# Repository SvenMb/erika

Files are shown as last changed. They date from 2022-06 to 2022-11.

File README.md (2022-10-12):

## Use your erika typewriter as keyboard and printer (and mouse)

System overview

### Compatible systems

You need a system with uinput (like linux), python3 and a TTL-serial port with CTS (can be done via usb-serial adapter).

I use a raspberry, because of this everything will be tested and prepared to use it this way. 

### Install

see [here](doc/install.md)

### Printing

It is possible to print with utf-8 coding and cp858 (cp850 + €) coding

### Use together with RunCPM

with a very small patch you can use the erika as "lst:" in RunCPM. Printing will be done without delay, every char will be printed directly.

Patch file: [RunCPM.patch](doc/RunCPM.patch)

orig Repository: [https://github.com/MockbaTheBorg/RunCPM.git](https://github.com/MockbaTheBorg/RunCPM.git)

#### Addendum

- serial printing doesnẗ work on DEBIAN sid via cups, use lpd or this hack until I implemented it directly:
~~~
socat TCP-LISTEN:9100 GOPEN:/dev/erika/erika
~~~

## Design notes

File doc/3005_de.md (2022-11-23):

# German keyboard layout for Erika 3005,3006,3015,3016
*(and compatible)*

To use the typewriter keyboard as computer keyboard some keys are
mapped to different chars, since these are needed for computer use.

Especialy for terminal use, you will need control keys, most of them
are mapped to CODE+A - CODE-Z, see below for more details.

The 3005 typewriter has an aditional layer via MODE key avaiable. 
So I could add special keys like cursor and mouse.
The cursor keys are arranged to wasd standard.
See below for details.

## Overview layout

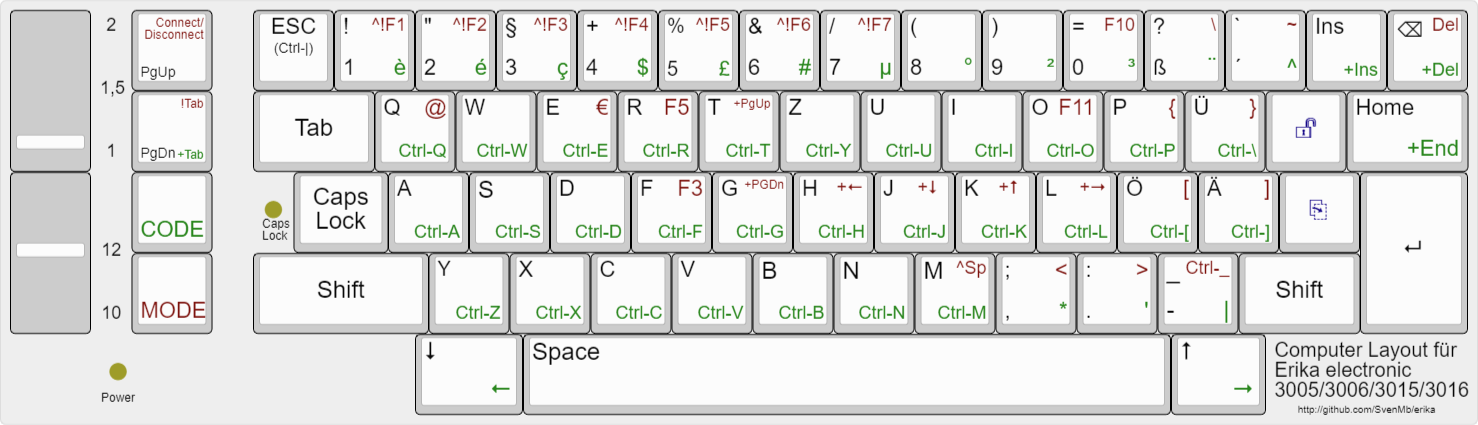
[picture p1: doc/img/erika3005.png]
Erika 3005 keyboard

(created with http://www.keyboard-layout-editor.com/)

notes:
- on 3006and 3016 the switches are labeled different, but they aren't used in computer connection any way
- mouse keys are not included in this picture
- Connect/Disconnect's the typewriter from computer as keyboard or standalone use as typewriter
- red description means the key is pressed together with MODE-key
- green description means the key is pressed together with  
- \+ means Shift, so +Tab means it sends Shift+Tab
- ! means Alt, so !Tab means it sends Alt+Tab
- ^ means CTRL
- the above can be combined, so ^!F1 means CTRL-ALT-F1, which switches to first console on Linux
- ^Sp means CTRL-Space which is "set-mark" in emacs
- arrow mean cursor key
- ⌫ means Backspace or DeleteLeft
<!-- - ![unlock](https://raw.githubusercontent.com/ijprest/keyboard-layout-editor/master/font-src/kbd-webfont/Unicode-Lock-Open-1.svg) -->
- unlock this is border unlock key, currently not used
- unlock this is form feed key, it allows to load paper even in connected mode
- CTRL-Y and CTRL-Z are swapped, so wordstar diamond works as intended

## Standard chars
- all char keys just generate that char pictured on the key
- acute key is used to generate composed chars (like é,è,ê)
- shift-ß is also used to generate composed chars (like ë)

### additional chars
key code | key                  | char generated
-----|--------------------------|------------
0xdf | MODE+,			| <
0xe3 | MODE+.			| >
0xe5 | MODE+P			| {
0xe6 | MODE+Ö			| [
0xe8 | MODE+ß			| \
0xe9 | MODE+Ü			| }
0xea | MODE+Ä			| ]
0xec | MODE+`			| ~
0xc1 | MODE+Q			| @
0xc9 | MODE+E			| €

### special functions

 key code | key | function
------|-----|----------
0x72  | backstep/backspacer	| insert
0x75  | half line forward	| cursor down
0x76  | half line backward	| cursor up
0x77  | Carriage return 	| Enter
0x79  | Tab			| Tab
0x7a  | T+			| Page up
0x7b  | T-			| Page down
0x7e  | Margin setting left 	| ESC
0x80  | Margin release 		|
0x83  | Form feed/paper insert	| forward form feed
0x84  | 1 line spacing		|
0x85  | 1,5 line spacing	|
0x86  | 2 lines spacing		|
0x87  | 10 cpi/ type spacing	|
0x88  | 12 cpi/ type spacing	|
0xae  | backspace/correction	| Backspace
0xaf  | REL			| Home

#### special chars with CODE

 key code | key | function
------|-----|----------
0x74  | CODE backstep/backspace   | shift insert
0xf7  | CODE backspace/correction | shift delete
0x7f  | Margin setting right	  | CTRL-ESC
0x7c  | CODE T-			  | shift-tab
0x7d  | CODE T+			  | mouse step width
0x81  | CODE micro line forward	  | cursor left
0x82  | CODE micro line backward  | cursor right
0xad  | CODE REL		  | shift End

#### special chars with MODE
 key code | key | function
----------|-----|----------
0xfb  | MODE backspace/correction | delete
0xf4	  | MODE T+    | switch computer/typewriter
0xf5	  | MODE T-    | ALT-tab (switch window)
0xc1	  | MODE 1     | CTRL-ALT-F1 (switch tty1)
0xc4	  | MODE 2     | CTRL-ALT-F2 (switch tty2)
0xc8	  | MODE 3     | CTRL-ALT-F3 (switch tty3)
0xcc	  | MODE 4     | CTRL-ALT-F4 (switch tty4)
0xd0	  | MODE 5     | CTRL-ALT-F5 (switch tty5)
0xd4	  | MODE 6     | CTRL-ALT-F6 (switch tty6)
0xd8	  | MODE 7     | CTRL-ALT-F7 (switch tty7)
0xdc	  | MODE 8     |
0xe0	  | MODE 9     |
0xe4	  | MODE 0     | F10 (Menu in Emacs)
0xe8	  | MODE O     | F11 (fullscreen)
0xcd	  | MODE R     | F5  (refresh)
0xce	  | MODE F     | F3  (find)
0xd3  | MODE M      | CTRL-Space (set-mark emacs)

### CTRL keys
**from CODE A until CODE Z - generate corresponding CTRL-A until CTRL-Z**

 key code | key    | function
----------|--------|----------
0xbb+0xe9 | CODE-Ü | CTRL-\ 0x1c
0xbb+0xe6 | CODE-Ö | CTRL-[ 0x1b
0xbb+0xea | CODE-Ä | CTRL-] 0x1d (telnet-Escape)
          |        | CTRL-^ 0x1e (not implemented, use ESC)
0xe7	     | MODE-_ | CTRL-_ 0x1f

### Cursor keys
key code | key | function
---------|-----|----------
0x75  | half line forward	  | cursor down
0x76  | half line backward	  | cursor up
0x81  | CODE micro line forward	  | cursor left
0x82  | CODE micro line backward  | cursor right
0x7a  | T+			  | Page up
0x7b  | T-			  | Page down
0xe2  | MODE L 			  | shift cursor rigth
0xda  | MODE J 			  | shift cursor down
0xde  | MODE K 			  | shift cursor up
0xd6  | MODE H 			  | shift cursor left
0xd1  | MODE T 			  | shift page up
0xd2  | MODE G 			  | shift page down
0xeb  | REL 			  | HOME
0xee  | CODE REL		  | END

### Mouse keys
key code | key          | function
---------|--------------|----------
0x7d	 | CODE T+	| step width for mouse (1,4,8,16)
0xc3 	 | MODE Y	| mouse btn left
0xcb 	 | MODE C  	| mouse btn right 
0xc7 	 | MODE X	| mouse btn left on (tap step down for off)
0xcf 	 | MODE V	| mouse btn right on (tap step up for off)
0xc2 	 | CODE A 	| mouse left
0xc6 	 | CODE S 	| mouse down
0xc5 	 | CODE W 	| mouse up
0xca 	 | CODE D 	| mouse right

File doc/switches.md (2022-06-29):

# keycodes and states for switches

## keycodes send by erika 3004/3005/3006/3015/3016

Even if the switches on the left side of the keyboard have different meaning on 3005 and 3006 they send same key codes.
Only 3004 send different codes.

I have tested all the erika models  and got that table:

switch                   | 3004 | 3005 | 3006 | 3015 | 3016
-------------------------|------|------|------|------|------
upper switch, upper pos  | 0x86 | 0xf8 | 0xf8 | 0xf8 | 0xf8
upper switch, middle pos | 0x85 | 0xfe | 0xfe | 0xfe | 0xfe
upper switch, lower pos  | 0x84 | 0xf9 | 0xf9 | 0xf9 | 0xf9
lower switch, upper pos  | 0x88 | 0xff | 0xff | 0xff | 0xff
lower switch, lower pos  | 0x87 | 0xfa | 0xfa | 0xfa | 0xfa

so from 3005 and up there is a special code for the switches, while 3004 send it as state of typewriter.

## when sending the disconnect code (0x92)

*this code disconnects the typewriter from the keyboard, for computer use and send information about the state of the typewriter*

### erika 3004

* sends only state of typewriter and switches together
  * state of cpi, one of:
    * 0x87 - 10cpi
    * 0x88 - 12cpi
  * state of line spacing, one of
    * 0x84 - 1 line
    * 0x85 - 1,5 line
    * 0x86 - 1,5 line

*be aware erika 3004 may send 0x85 (0x85) first and then the correct line spacing.*

### erika 3005, 3006, 3015, 3016

* sends state of typewriter
  * state of cpi, one of:
    * 0x87 - 10cpi
    * 0x88 - 12cpi
    * 0x89 - 15cpi
  * state of line spacing, one of
    * 0x84 - 1 line
    * 0x85 - 1,5 line
    * 0x86 - 1,5 line

* sends state of switches
  * one byte for each switch (2), see above table

### Conclusion

based on this it is possible to auto switch between 3004 and 3005 (and other models with mode key)

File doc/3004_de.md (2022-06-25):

# German keyboard layout for Erika 3004
*(and compatible)*

To use the typewriter keyboard as computer keyboard some keys are
mapped to different chars, since these are needed for computer use.
(see changed chars)

Especialy for terminal use, you will need control keys, most of them
are mapped to CODE+A - CODE-Z, see below for more details.

You will probably need special keys like cursor and I liked to
emulate a mouse. This is realized in second layer of the keyboard
you have to switch between them. The cursor keys are arranged like
the wordstar diamond. See below for details.

## 1st layer
- nearly all char keys just generate that char pictured on the key
- acute key is used to generate composed chars (like é,è,ê)
- 2nd layer shift-ß is also used to generate composed chars (like ë)

### switch to 2nd layer
key code | key | function
---------|-----|----------
0x78 | backstep left to enter	| switch to 2nd layer

### changed chars
key code | key                  | char generated
-----|--------------------------|------------
0x46 | CODE+1 (è)		| @
0x44 | CODE+2 (é)		| ~
0x45 | CODE+3 (ç)		| €
0x06 | CODE+5 (£)		| <
0x07 | CODE+7 (µ)		| >
0x03 | CODE+ß (")		| \
0xe9 | CODE+Ü			| {
0x80 | Margin release		| } (works with CODE too)
0xe6 | CODE+Ö			| [
0xea | CODE+Ä			| ]

### special functions

 key code | key | function
------|-----|----------
0x72  | backstep/backspacer	| insert
0x75  | half line forward	| cursor down
0x76  | half line backward	| cursor up
0x77  | Carriage return 	| Enter
0x79  | Tab			| Tab
0x7a  | T+			|  CTRL-_ (undo in emacs)
0x7b  | T-			| shift Tab
0x7e  | Margin setting left 	| ESC
0x80  | Margin release 		| } (that char!)
0x83  | Form feed/paper insert	| forward form feed
0x84  | 1 line spacing		|
0x85  | 1,5 line spacing	|
0x86  | 2 lines spacing		|
0x87  | 10 cpi/ type spacing	|
0x88  | 12 cpi/ type spacing	|
0xae  | backspace/correction	| Backspace
0xaf  | REL			| Delete

#### special chars with CODE

 key code | key | function
------|-----|----------
0x74  | CODE backstep/backspace	| shift insert
0x7f  | Margin setting right	| CTRL-ESC
0x7c  | CODE T-			| ALT-Tab
0x7d  | CODE T+			| switch computer/typewriter
0x81  | CODE micro line forward	| cursor left
0x82  | CODE micro line backward| cursor right
0xad  | CODE REL		| shift Delete

**from CODE A until CODE Z - generate corresponding CTRL-A until CTRL-Z**

## 2nd layer

Cursor and mouse keys stay in 2nd-layer so you can move around easiliy.

### switch back to 1st layer
key code | key | function
---------|-----|----------
0x77     | Carriage return	| switch back to 1st layer

*and all other keys not mentioned here as cursor or mouse key*

### Cursor keys
key code | key | function
---------|-----|----------
0x14 | shift D 			| shift cursor rigth
0x20 | shift C 			| shift page down
0x26 | shift X 			| shift cursor down
0x33 | shift S 			| shift cursor left
0x34 | shift E 			| shift cursor up
0x36 | shift R 			| shift page up
0x4c | W 		| Home
0x51 | Y 			| End
0x53 | D 			| cursor right
0x57 | C 			| page down
0x58 | S 			| cursor left
0x59 | R 			| page up
0x5a | E 			| cursor up
0x5f  | X 			| cursor down

### Mouse keys
key code | key | function
---------|-----|----------
0x75 | half line forward	| mouse btn left
0x76 | half line backward  	| mouse btn right 
0x7a | T+			| step width for mouse (1,4,8,16)
0x81 | CODE micro line forward	| mouse btn left on (tap step down for off)
0x82 | CODE micro line backward | mouse btn right on (tap step up for off)
0xc3 | CODE Y 			| mouse down+left
0xc5 | CODE W 			| mouse up+left
0xc6 | CODE S 			| mouse left
0xc7 | CODE X 			| mouse down
0xc9 | CODE E 			| mouse up
0xca | CODE D 			| mouse right
0xcb | CODE C 			| mouse down+right
0xcd | CODE R 			| mouse up+right

### Function keys
**starting from here all keys switch back to 1st layer after using**

key code | key | function
---------|-----|----------
0x11 | 1 			| F1
0x10 | 2 			| F2
0x0f | 3 			| F3
0x0e | 4 			| F4
0x0c | 5 			| F5
0x0b | 6 			| F6
0x0a | 7 			| F7
0x09 | 8 			| F8
0x08 | 9 			| F9
0x0d | 0 			| F10
0x47 | ß 			| F11
0x29 | ` 			| F12
0x46 | CODE 1 			| CTRL ALT F1
0x44 | CODE 2 			| CTRL ALT F2
0x45 | CODE 3 			| CTRL ALT F3
0x48 | CODE 4 			| CTRL ALT F4
0x06 | CODE 5 			| CTRL ALT F5
0x41 | CODE 6 			| CTRL ALT F6
0x07 | CODE 7 			| CTRL ALT F7
0x39 | CODE 8 			| CTRL ALT F8
0x15 | CODE 9 			| CTRL ALT F9
0x23 | CODE 0 			| CTRL ALT F10

### some more CTRL-keys and chars

key code | key | function/char
---------|-----|---------------
0xe6 | CODE Ö 			| ^[, (CTRL-[, 0x1b | ESC)
0x03 | CODE ß 			| ^\, (CTRL-\, 0x1c)
0xea | CODE Ä 			| ^], (CTRL-], 0x1d)
0x19 | CODE ` 			| ^^, (CTRL-^, 0x1e)
0x27 | CODE _ 			| ^_, (CTRL-_, 0x1f)
0x3d | shift 3			| ç, (that char)
0x35 | shift ß			| ", to generate composed char
0x7d | CODE T+    | "shutdown -h now" if next key is y

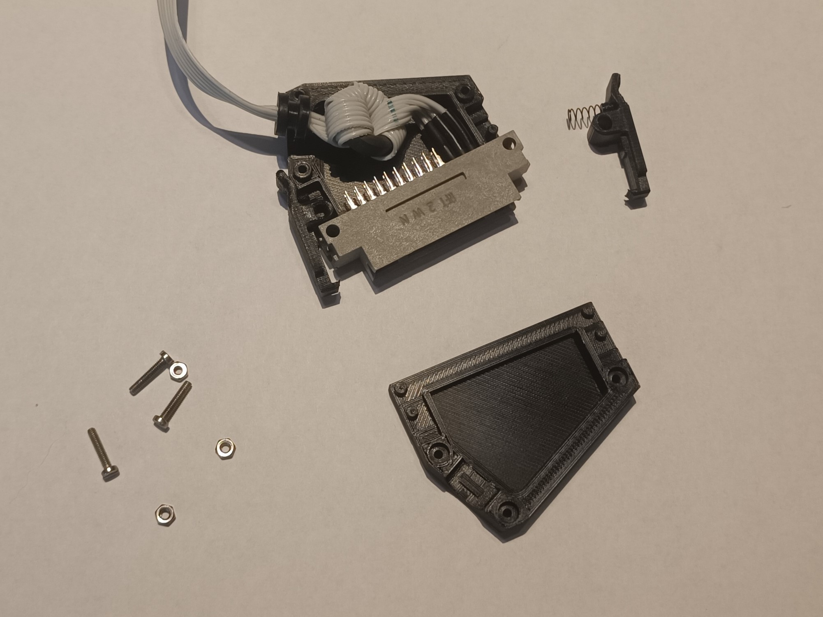
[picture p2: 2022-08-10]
hardware/efs26_con01.jpg

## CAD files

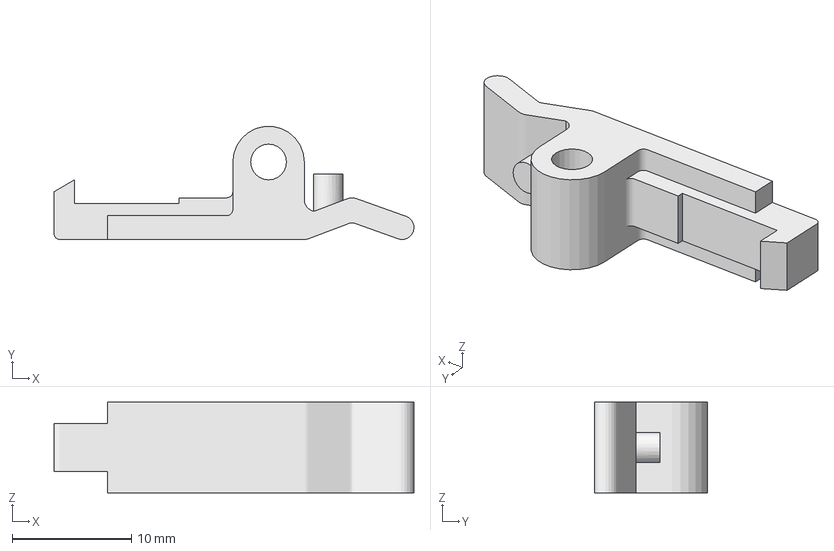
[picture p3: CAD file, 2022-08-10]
hardware/efs26_gehaeuse_hebel.FCStd
30.2 x 9.48 x 7.60 mm

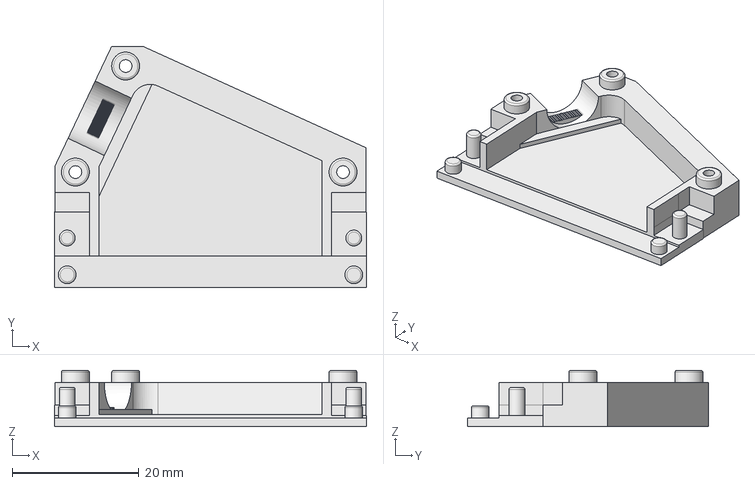
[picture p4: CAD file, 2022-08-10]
hardware/efs26_gehaeuse_oben.FCStd
49.2 x 38.0 x 8.90 mm

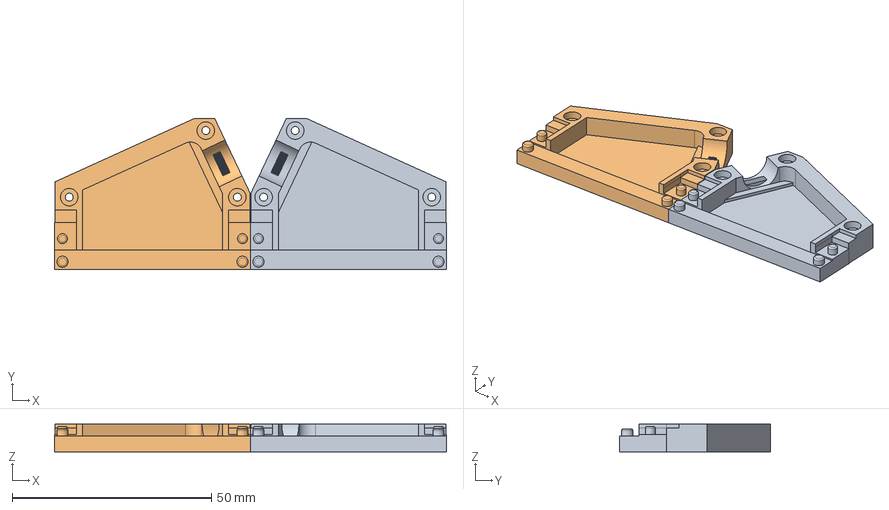
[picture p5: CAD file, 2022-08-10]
hardware/efs26_gehaeuse_unten.FCStd
98.4 x 38.0 x 7.00 mm
untereSchale
Fillet (Mirror #1)

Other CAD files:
hardware/efs26_gehaeuse_Hebel.stl
hardware/efs26_gehaeuse_oben.stl
hardware/efs26_gehaeuse_unten.stl

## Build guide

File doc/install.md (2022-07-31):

## Install erika service

### Prerequisites

You will need a installed linux system with working /dev/uinput and serial
connection with hardware rts/cts flow control.
If you like to use the service definitions, you also need systemd, else 
you need to integrate it in your system by yourself.

#### example raspberry Erika on GPIO header

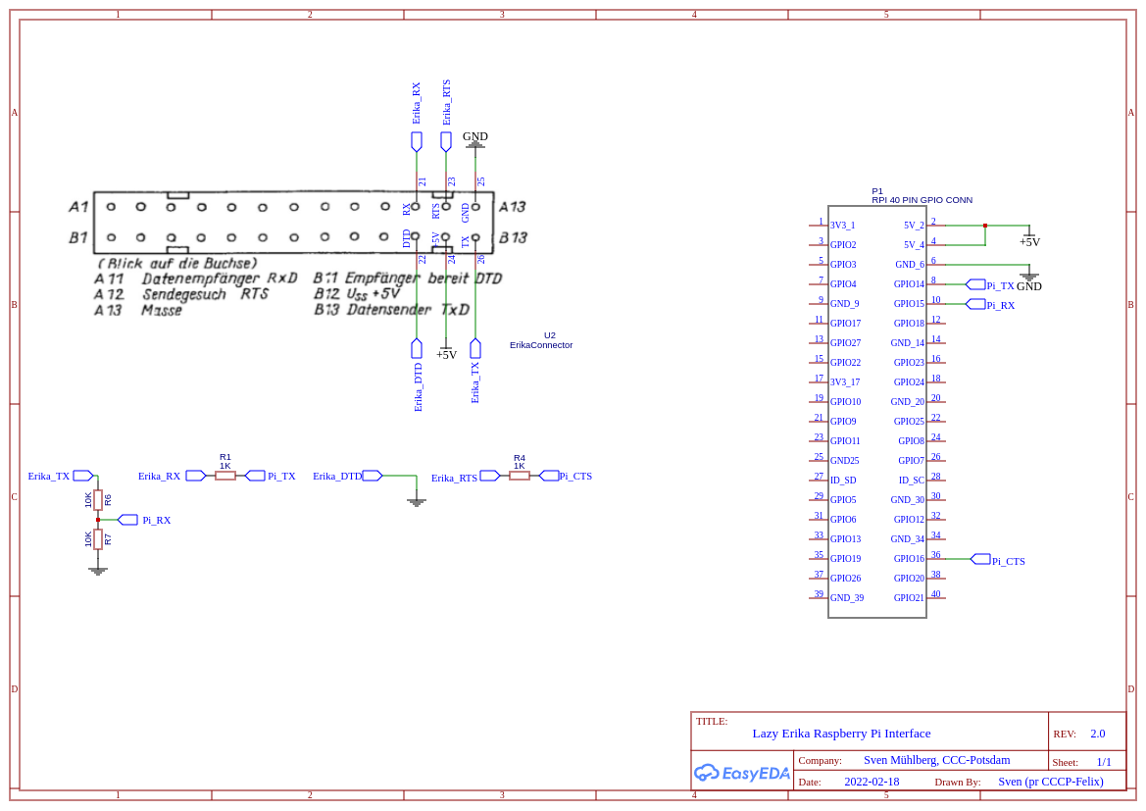
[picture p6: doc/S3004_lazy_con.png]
Erika2raspberry

*5v should only be connected if you like to power the raspberry from you Erika. And this should only be done with a low power raspi like Zero, Zero W maybe with Zero W 2.* 

1. install raspberry
2. take care, that serial port is enabled, but login shell on serial is off. keymap should be de for 105keys keyboard, since currently only german keymap is available. 
(all done via raspi-config)
3. copy the uart-cts to overlays  
`sudo cp raspberry/boot/overlays/uart-cts.dtbo /boot/overlays/`  
4. add following lines to config.txt (first one should already be there)
```
enable_uart=1
dtoverlay=miniuart-bt
dtoverlay=uart-cts
```
This makes sure that uart is enabled, the right uart is assigned to gpio port (and bluetooth get the simpler one and will also work).
It activates CTS on GPIO16 (pin 36 on gpio header)

#### known problems with ch34x serial-usb adapter

In case you like to use a ch340 USB-Serial adapter, then this info is for you.

The ch34x has a CTS pin but even when CTS pin is avaiable on your adapter hardware flow controll probably won't work, since default linux kernel driver ignores CTS and sends data even when it should stop.

A working driver for current linux kernel can be found here:

[https://github.com/juliagoda/CH341SER](https://github.com/juliagoda/CH341SER)

### manual installation from https://git.muehlberg.net

1. Verzeichnis erstellen
```sh
cd
mkdir -pv Development/SvenMb
cd Development/SvenMb
```
1. extract certificate for git.muehlberg.net:  
```sh
echo -n \\ | openssl s_client -showcerts -connect git.muehlberg.net:443 \
2>/dev/null  | sed -ne '/-BEGIN CERTIFICATE-/,/-END CERTIFICATE-/p' \
> mbnet_cert.pem
```
2. add the cert to your git config  
`git config --global http."https://git.muehlberg.net:443/".sslCAInfo $(pwd)/mbnet_cert.pem`
3. clone project directory  
`git clone https://git.muehlberg.net/SvenMb/erika.git`
4. change to project directory  
`cd erika`
5.  install python-evdev  
`sudo apt install python3-evdev` (z.Z. nur v1.4) oder 
`sudo pip3 install evdev` (aktuell v1.6)
6.  copy src to /var/lib/erika  
`sudo cp -R src /var/lib/erika`
7.  link /var/lib/erika/erika_set.py to /usr/bin/
`sudo ln -s /var/lib/erika/erika_set.py /usr/bin/`
8. copy systemd/system/erika.service to /etc/systemd/system/erika.service  
`sudo cp systemd/system/erika.service /etc/systemd/system/erika.service`
9. copy systemd/default/erika.service to /etc/default/erika  
`sudo cp systemd/default/erika /etc/default/erika`
10. change to cups directory
`cd cups`
11. start cups install script
`./create_ppd.sh`

### adapt to local system

* you can set different serial ports and other options in /etc/default/erika
* you can adjust the virtual printer port permission and name in /var/lib/erika/setperm.sh

### test service

* start erika service  
  `sudo systemctl start erika`
* get status of erika service  
  `sudo systemctl status erika`
* stop erika service  
 `sudo systemctl stop erika`

### enable service for autostart 

* enable service for default start  
  `sudo systemctl enable erika`

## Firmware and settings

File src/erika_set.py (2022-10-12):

#!/usr/bin/env python3
# -*- coding: utf-8 -*-
#
#  erika_set.py
#  
#  Copyright 2022  <sven@muehlberg.net>
#  
#  

import serial
import os, sys, getopt

def eprint(*args, **kwargs):
    print(*args, file=sys.stderr, **kwargs)

def main(argv):

    s          = serial.Serial()
    s.port     = '/dev/erika/erika'
    
    verbose    = 0
    cpi        = None
    linestep   = None
    maxlines   = None
    maxcolumns = None
    tabstop    = None
    charset    = None
    firstcol   = None
    formfeed   = False
    wrap       = None
    backsteps  = None

    # comand line args
    try:
        opts, args = getopt.getopt(argv,"hvd:i:s:l:c:f:w:t:z:B:p",
            ["help","verbose","device=","cpi=","halflines=","columns=","firstcolumn=","linespacing=","wrap=","tabstop=","charset=","backsteps=","formfeed"])
    except getopt.GetoptError:
        eprint('erika.py argument error')
        eprint('use erika_set.py -h for help')
        sys.exit(2)

    if len(opts) == 0:
        eprint('erika_set.py no argument error')
        eprint('use erika_set.py -h for help')
        sys.exit(2)

    for opt, arg in opts:
        if opt in ('-h', '--help'):
            print('erika_set.py\n')
            print('USAGE:')
            print('\terika_set.py [OPTIONS]\n')
            print('OPTIONS:')
            print('\t-h, --help\t\tprint help information')
            print('\t-v, --verbose\t\tbe more verbose')
            print('\t\tcan be added multiple times to be even more verbose')
            print('\t-d, --device <device>\tserial device to use')
            print('\t\tdefault: ', s.port )
            print('\t\tif \'-\' is given as devicename, stdout is used')
            print('\t-i, --cpi\t\tcharacters per inch, char density')
            print('\t\tuse 10, 12 with normal daisy wheel, 15 possible on\n\t\t3005(and up) with special daisy wheel')
            print('\t-s, --linespacing\t\thalf lines used for one printed line')
            print('\t\tpossible spacing: 2, 3, 4')
            print('\t-l, --halflines\t\tmax half lines per paper sheet')
            print('\t\tA4 - 120 half lines')
            print('\t-c, --columns\t\tmax half char per line')
            print('\t\trecommended:')
            print('\t\tA4 - 84 columns on 12 cpi')
            print('\t\tmax 150 columns')
            print('\t-f, --firstcolumn\t\tfirst column')
            print('\t\trecommended 10 for 10cpi, 12 for 12cpi and 15 for 15cpi')
            print('\t\tstarting with 1')
            print('\t-w, --wrap\t\tLinewrapping on or off')
            print('\t\t1 for wrapping to long lines and 0 for truncating')
            print('\t-t, --tabstop\t\tdistance tabstops')
            print('\t\trecommended 4 or 8')
            print('\t-B, --backsteps\t\thalf steps backward after formfeed')
            print('\t\tpossible between 0 and 9')
            print('\t-z, --charset\t\textra charset (Zeichenkodierung)')
            print('\t\tselectable from cp858 and if6000')
            print('\t\tmain charset is always utf-8')
            print('\t-p, --formfeed\t\tform feed to change paper')
            print('\t\tno options')
            sys.exit()
        elif opt in ('-d', '--device'):
            s.port = arg
        elif opt in ('-v', '--verbose'):
            verbose += 1
        elif opt in ('-i', '--cpi'):
            if arg in ('10','12','15'):
                cpi = arg
            else:
                eprint('ERROR: Wrong cpi:', arg)
                eprint('ERROR: only 10, 12 or 15 possible')
                sys.exit(2)
        elif opt in ('-s', '--linespacing'):
            if arg in ('2', '3', '4'):
                linestep=arg
            else:
                eprint('ERROR: wrong linespacing:',arg)
                eprint('ERROR: only 2, 3 or 4 possible')
                sys.exit(2)
        elif opt in ('-l', '--halflines'):
            if arg.isnumeric() and int(arg) < 256:
                maxlines = int(arg)
            else:
                eprint('ERROR: wrong halflines ',arg,' used.')
                sys.exit(2)
        elif opt in ('-c', '--columns'):
            if arg.isnumeric() and int(arg) < 151:
                maxcolumns = int(arg)
            else:
                eprint('ERROR: wrong columns ',arg,' used.')
                sys.exit(2)
        elif opt in ('-f','--firstcolumn'):
            if arg.isnumeric() and int(arg) > 0:
                firstcol = int(arg)
            else:
                eprint('ERROR: wrong firstcolumn',arg)
                sys.exit(2)
        elif opt in ('-w','--wrap'):
            if arg in ('0','1'):
                wrap = arg
            else:
                eprint('ERROR: wrong LineWrap:',arg)
                eprint('ERROR: only 0 or 1 possible here.')
                sys.exit(2)
        elif opt in ('-t', '--tabstop'):
            if arg.isnumeric() and int(arg) > 0 and int(arg) < 17:
                tabstop = int(arg)
            else:
                eprint('ERROR: wrong tabstop:',arg)
                eprint('ERROR: tabstop should between 1 and 16 spaces')
                sys.exit(2)
        elif opt in ('-B', '--backsteps'):
            if arg.isnumeric() and int(arg) < 10:
                backsteps = int(arg)
            else:
                print('wrong backsteps ',arg,' used.')
                sys.exit(2)
        elif opt in ('-z', '--charset'):
            if arg in ('cp858','if6000'):
                charset = arg
            else:
                eprint('ERROR: wrong extra charset',arg)
                sys.exit(2)
        elif opt in ('-p','--formfeed'):
            formfeed = True



    # info about current options         
    if verbose:
        eprint('DEBUG: Erika device:', s.port)
        eprint('DEBUG: verbose      :',verbose)
        if cpi:
            eprint('DEBUG: cpi          :', cpi)
        if maxcolumns:
            eprint('DEBUG: maxcolumns   :', maxcolumns)
        if linestep:
            eprint('DEBUG: linestep     :', linestep)
        if maxlines:
            eprint('DEBUG: maxlines     :', maxlines)
        if firstcol:
            eprint('DEBUG: firstcolumn  :', firstcol)
        if wrap:
            eprint('DEBUG: tabstop      :', wrap)
        if tabstop:
            eprint('DEBUG: tabstop      :', tabstop)
        if charset:
            eprint('DEBUG: extra charset:', charset)
        if backsteps!=None:
            eprint('DEBUG: backsteps    :', backsteps)
        if formfeed:
            eprint('DEBUG: formfeed     :', formfeed)

    # open erika port
    if s.port != '-':
        try:
            s.open()
        except serial.SerialException as e:
            eprint(e)
            eprint('CRIT: erika daemon not running or wrong device name')
            eprint('CRIT: use erika_set.py -h for help')
            sys.exit(2)
    # or stdout
    else:
        s = os.fdopen(sys.stdout.fileno(), 'wb',closefd=False)
    # cpi
    if cpi:
        if cpi == '15':
            s.write(b'\x1bO')
        elif cpi == '12':
            s.write(b'\x1bN')
        else: # should be 10 now
            s.write(b'\x1bM')
        eprint('INFO: cpi set to        :', cpi)

    # linespacing
    if linestep:
        if linestep == '2':
            s.write(b'\x1b3')
        elif linestep == '3':
            s.write(b'\x1b4')
        else: # should be 4 now
            s.write(b'\x1b5')
        eprint('INFO: linespacing set to:', linestep)

    # maxlines
    if maxlines:
        s.write(b'\x1bL' + maxlines.to_bytes(1,'big'))
        eprint('INFO: maxlines set to:', maxlines)

    # maxcolumns
    if maxcolumns:
        s.write(b'\x1bC' + maxcolumns.to_bytes(1,'big'))
        eprint('INFO: maxcolumns set to:', maxcolumns)

    # firstcolumn
    if firstcol:
        s.write(b'\x1bF' + firstcol.to_bytes(1,'big'))
        eprint('INFO: firstcolumn set to:', firstcol)

    # wrap
    if wrap:
        if wrap == '0':
            s.write(b'\x1bw')
        else:
            s.write(b'\x1bW')
        eprint('INFO: wrap set to:', wrap)

    # tabstop
    if tabstop:
        s.write(b'\x1bT' + tabstop.to_bytes(1,'big'))
        eprint('INFO: tabstop set to:', tabstop)

    # charset
    if charset:
        if charset == 'cp858':
            s.write(b'\x1bZ')
        else: # should be if6000
            s.write(b'\x1bz')
        eprint('INFO: charset set to:', charset)

    # backsteps
    if backsteps!=None:
        s.write(b'\x1bB' + backsteps.to_bytes(1,'big'))
        eprint('INFO: backsteps set to:', backsteps)
    
    # form feed
    if formfeed:
        s.write(b'\f')
        eprint('INFO: form feed sent to erika')
        eprint('INFO: use \'margin release\' key when finished')

    s.flush()
    s.close()
    sys.stderr.flush()

    
if __name__ == "__main__":
    main(sys.argv[1:])

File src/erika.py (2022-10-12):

#!/usr/bin/env python3
# -*- coding: utf-8 -*-
#
#  erika.py
#  
#  Copyright 2022  <sven@muehlberg.net>
#  
#  

from erika.erika import Erika
import erika.vprint as V
import sys, getopt

verbose = 0

def main(argv):
    
    e = Erika()

    V.init()
    
    # comand line args
    try:
        opts, args = getopt.getopt(argv,"hved:b:k:p:i:s:l:c:f:wt:B:z:",
            ["help","verbose","echo","device=","baudrate=","keyboard=",'setperm=','cpi=','linespacing=','halflines=','columns=','firstcolumn=','wrap','tabstop=','backsteps=','charset='])
    except getopt.GetoptError:
        print('erika.py argument error')
        print('use erika.py -h for help')
        sys.exit(2)
    for opt, arg in opts:
        if opt in ('-h', '--help'):
            print('erika.py\n')
            print('USAGE:')
            print('\terika.py [OPTIONS]\n')
            print('OPTIONS:')
            print('\t-h, --help\t\tprint help information')
            print('\t-v, --verbose\t\tbe more verbose')
            print('\t\tcan be added multiple times to be even more verbose')
            print('\t-e, --echo\t\tconnect keyboard to typewriter')
            print('\t-d, --device <device>\tserial device to use')
            print('\t\tExample device name: /dev/ttyAMA0 or /dev/ttyUSB0')
            print('\t\tdefault: ', e.serial.port )
            print('\t-b, --baudrate <rate>\tbaudrate for erika')
            print('\t\terika manual says don\'t change!')
            print('\t\tExample baudrate: 1200')
            print('\t\tdefault: ', e.serial.baudrate )
            print('\t-k, --keyboard <map>\tkeyboard map to use')
            print('\t\tpossible keyboards: de, 3004_de, 3005_de, none')
            print('\t\tdefault: ', e.keyboard )
            print('\t\tuse \'de\' for autodetect machine type (only\n\t\timplemented language currently)')
            print('\t\tuse \'none\' if you don\'t want to use the erika\n\t\tkeyboard for input')
            print('\t\tcurrently implemented 3004_de and 3005_de.')
            print('\t\t3005, 3006, 3015, 3016 use the same keycodes.')
            print('\t-p, --setperm <script>\tscript to create link and set\n\t\tpermission for virtual lp-device')
            print('\t\tExample: sudo lp_setperm')
            print('\t\tdefault: ', e.lpsetperm )
            print('\t-i, --cpi\t\tcharacters per inch, char density')
            print('\t\tdefault: ', int(60/e.charstep))
            print('\t\tuse 10, 12 with normal daisy wheel, 15 possible on\n\t\t3005(and up) with special daisy wheel')
            print('\t-s, --linespacing\t\thalf lines used for one printed line')
            print('\t\tpossible spacing: 2, 3, 4')
            print('\t\tdefault: ',e.linestep)
            print('\t-l, --halflines\t\tmax half lines per paper sheet')
            print('\t\tdefault: ', e.maxlines)
            print('\t\tA4 - 120 half lines')
            print('\t-c, --columns\t\tmax half char per line')
            print('\t\tdefault: ', int(e.maxcolumns/e.charstep))
            print('\t\tA4 - 84 columns on 12 cpi')
            print('\t-f, --firstcolumn\t\tfirst column')
            print('\t\tdefault: ', e.firstcol)
            print('\t\trecommended 10 for 10cpi, 12 for 12cpi and 15 for 15cpi')
            print('\t\tstarting with 1')
            print('\t-w, --wrap')
            print('\t\tdefault: off')
            print('\t\tIf this option is given, to long lines will be wrapped around,')
            print('\t\tif not, they will be truncated.')
            print('\t-t, --tabstop\t\tdistance tabstops')
            print('\t\tdefault: ', e.tabstop)
            print('\t\trecommended 4 or 8')
            print('\t-B, --backsteps\t\thalf steps backward after formfeed')
            print('\t\tdefault: ', e.backsteps)
            print('\t\tpossible between 0 and 9')
            print('\t-z, --charset\t\textra charset (Zeichenkodierung)')
            print('\t\tdefault:',e.charset)
            print('\t\tselectable from cp858 and if6000')
            print('\t\tmain charset is always utf-8')
            sys.exit()
        elif opt in ('-e','--echo'):
            e.echo = True
        elif opt in ('-d', '--device'):
            e.serial.port = arg
        elif opt in ('-b', '--baudrate'):
            e.serial.baudrate = arg
        elif opt in ('-k', '--keyboard'):
            e.keyboard = arg
        elif opt in ('-p', '--setperm'):
            e.lpsetperm = arg
        elif opt in ('-i', '--cpi'):
            if arg in ('10','12','15'):
                e.charstep=int(60/int(arg))
            else:
                print('wrong cpi',arg,'used.')
                sys.exit(2)
        elif opt in ('-s', '--linespacing'):
            if arg in ('2', '3', '4'):
                e.linestep=int(arg)
            else:
                print('wrong linespacing ',arg,' used.')
                sys.exit(2)
        elif opt in ('-l', '--halflines'):
            if arg.isnumeric():
                e.maxlines = int(arg)
            else:
                print('wrong halflines ',arg,' used.')
                sys.exit(2)
        elif opt in ('-c', '--columns'):
            if arg.isnumeric():
                e.maxcolumns = int(arg)*charstep - 1
            else:
                print('wrong columns ',arg,' used.')
                sys.exit(2)
        elif opt in ('-f','--firstcolumn'):
            if arg.isnumeric() and int(arg) > 0:
                e.firstcol = int(arg)
            else:
                print('wrong firstcolumn',arg)
                sys.exit(2)
        elif opt in ('-w','--wrap'):
            e.wrap = True
        elif opt in ('-t', '--tabstop'):
            if arg.isnumeric():
                e.tabstop = int(arg)
            else:
                print('wrong tabstop ',arg,' used.')
                sys.exit(2)
        elif opt in ('-B', '--backsteps'):
            if arg.isnumeric() and int(arg) < 10:
                e.backsteps = int(arg)
            else:
                print('wrong backsteps ',arg,' used.')
                sys.exit(2)
        elif opt in ('-v', '--verbose'):
            print('verbose arg:',arg)
            V.inc()
        elif opt in ('-z', '--charset'):
            e.charset = arg
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

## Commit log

2022-06-13 added socat script with virtual serial device for devlopment
2022-06-20 Uebersetzung der keyboarddaten von erika begonnen
2022-06-23 modified uinput name handling; removed wheel option, since this program is not printing, just forwarding prints
2022-06-23 option wheel removed...
2022-06-23 added reboot on MODE+Randlösen
    [erika.py]
2022-06-24 change to mouse button handling
2022-06-24 added all keys (but currently empty on 2nd layer)
2022-06-24 small fix in s3004 keyboard
    [s3004_de.py]
2022-06-28 add info for raspberry pi
2022-06-29 doc added for switches
2022-06-29 begin rework keyboard, goal is to autodetect keyboard/typewriter model
    [erika.py, s3004_de.py, s3005_de.py]
2022-07-01 changed schematics
2022-07-01 added some infos to power raspberry from erika
2022-07-02 printing of utf-8/cp850 added
2022-07-02 printing now working
2022-07-03 line feed and line break when trying to print over paper borders added switching cpi and line spacing added verbose handling changed
2022-07-03 add carriage return if explicit form feed
2022-07-03 added charset from original if6000 and option + esc sequence to switch
2022-07-09 added stdout as device and made messages compatibel to cups
2022-07-11 cups driver nearly finished
2022-07-11 Install cups ppd/filter added
2022-07-11 backsteps implemented, some fixes
    [erika.py, erika_set.py]
2022-07-11 added filter for html and pdf
2022-07-11 path raspberry doc
2022-07-23 - service changed to restart on error (mainly when not detecting right keyboard) - left border now handled correctly on 3004 - removed try: except: for the deactivated unblocking lp device
    [erika.py]
2022-07-23 exported verbose messages to extra function fix xkey handling on 3004
    !!!! 3005 not working, need to adapt to vprint.msg !!!!!
    [erika.py, s3004_de.py]
2022-07-25 „doc/install.md“ ändern
2022-08-01 chars per line corrected for utf-8 multibyte chars
    [erika.py]
2022-08-07 connector housing for efs26
    [efs26_gehaeuse_hebel.FCStd, efs26_gehaeuse_oben.FCStd, efs26_gehaeuse_oben.stl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]
2022-08-10 exits when device vanishes
2022-08-10 added example udev rule for usb device
2022-09-06 „doc/3005_de.md“ ändern
2022-10-12 changed to python3 interpreter, since python symlink doesn`t exist on sid
    [erika.py, erika_set.py]
2022-10-12 small adaption... be more verbose and different usb device
2022-10-12 be more verbose, added install script for udev, change default device to usb
